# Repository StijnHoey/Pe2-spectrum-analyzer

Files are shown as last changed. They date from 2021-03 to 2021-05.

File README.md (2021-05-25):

# PCB's

## Informatie files:
Gebruikte tekenprogramma: Eagle 9.1.2 \
Eagle files: .sch & .brd \
Gerber files: .zip

### Informatie PCB's:
voedingequ:

Gebruikte Regelaars: LM317 & LM337 \
Emittervolger met zenerdiode: 2n3055

* Ingangsspanning:
  * 12V AC

* Uitgangsspanning:
  * -12V DC
  *   5V DC
  *  12V DC
  *  13v DC   

equlaizer:

Gebruikte OPAMP: LM072 \
Laagdoorlaatfilter en Hoogdoorlaatfilter.\
Samen opgeteld met sommeerversterker.\
Laagdoorlaatfilter voor bass.\
Hoogdoorlaatfilter voor treble. \
Versterking/verzwakking bepaald door digitale potentiometer.\
Digitale quad potentiometer: AD5263. \

Arduinoshield:\
Shield voor arduino om audio in te lezen.\
Voorzien van laagdoorlaatfilter.\
Offset regelbaar tot 3,3V.\

TDA7492:
25W stereo versterker. \
Aan/uit via shutdown pin en mute pin. \

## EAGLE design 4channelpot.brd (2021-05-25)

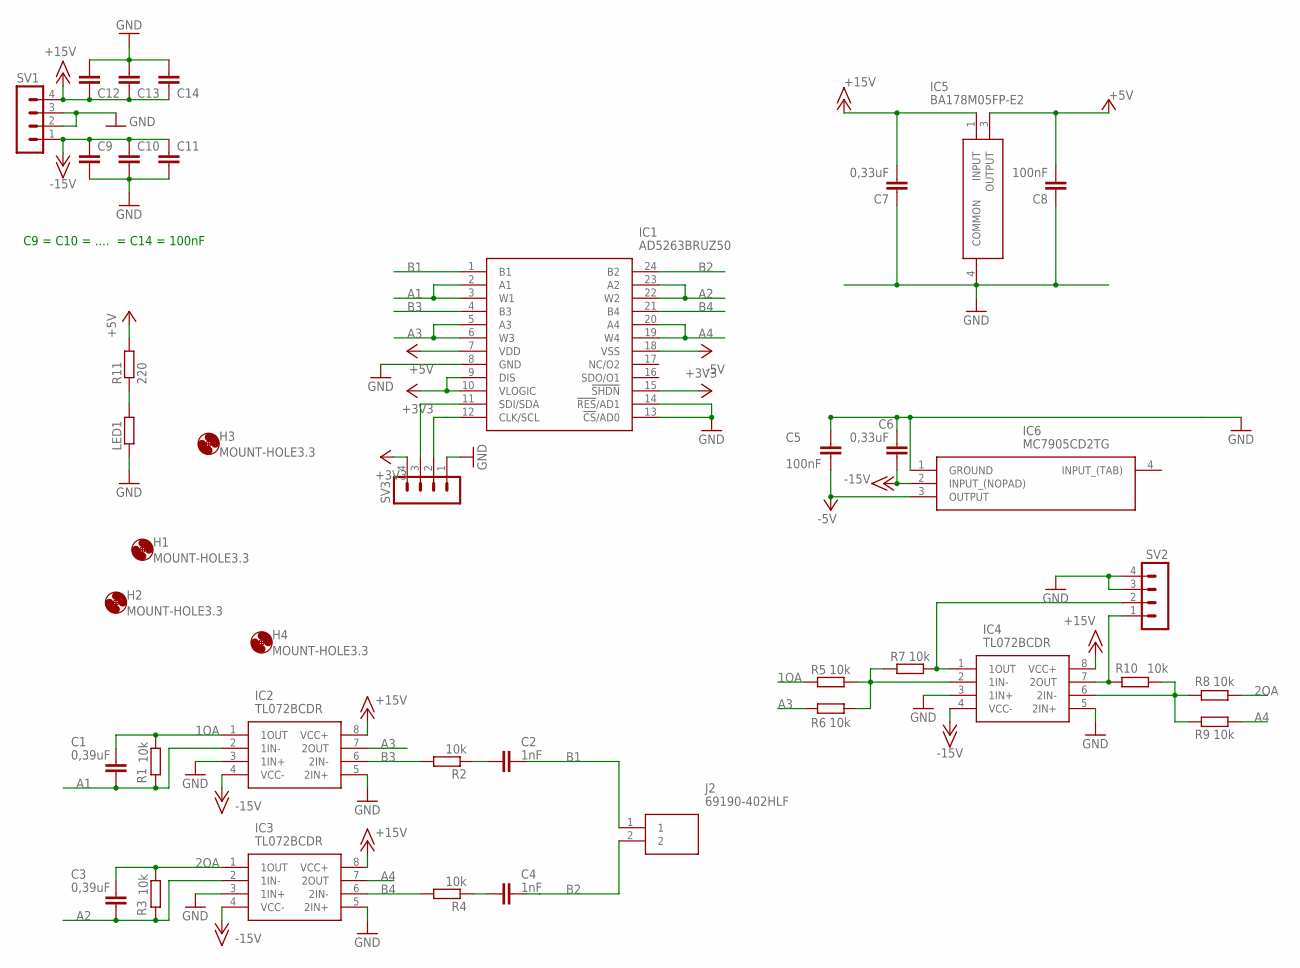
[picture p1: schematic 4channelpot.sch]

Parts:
C1, C3: 0,39uF; C0805
C2, C4: 1nF; C0805
C5, C8: 100nF; C0805
C6, C7: 0,33uF; C0805
C9, C10, C11, C12, C13, C14: C-EUC0805; C0805
H1, H2, H3, H4: MOUNT-HOLE3.3; 3,3
IC1: AD5263BRUZ50; SOP65P640X120-24N
IC2, IC3, IC4: TL072BCDR; SOIC127P600X175-8N
IC5: BA178M05FP-E2; BD750L5FPCE2
IC6: MC7905CD2TG; TO254P1420X457-4N
J2: 69190-402HLF; HDRV2W90P0X254_1X2_508X241X858
LED1: R-EU_R0805; R0805
R1, R2, R3, R4, R5, R6, R7, R8, R9, R10: 10k; R0805
R11: 220; R0805
SV1, SV2, SV3: MA04-1

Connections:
1OA: C1.1, IC2.1 (1OUT), R1.2, R5.2
2OA: C3.1, IC3.1 (1OUT), R3.2, R8.2
+3V3: IC1.9 (DIS), IC1.10 (VLOGIC), IC1.15 (!SHDN), SV3.4
+5V: C8.2, IC1.7 (VDD), IC5.3 (OUTPUT), R11.2
+15V: C7.2, C12.1, C13.1, C14.1, IC2.8 (VCC+), IC3.8 (VCC+), IC4.8 (VCC+), IC5.1 (INPUT), SV1.4
-5V: C5.2, IC1.18 (VSS), IC6.3 (OUTPUT)
-15V: C6.2, C9.1, C10.1, C11.1, IC2.4 (VCC-), IC3.4 (VCC-), IC4.4 (VCC-), IC6.2 (INPUT_(NOPAD)), SV1.1
A1: C1.2, IC1.2 (A1), IC1.3 (W1), IC2.2 (1IN-), R1.1
A2: C3.2, IC1.22 (W2), IC1.23 (A2), IC3.2 (1IN-), R3.1
A3: IC1.5 (A3), IC1.6 (W3), IC2.7 (2OUT), R6.2
A4: IC1.19 (W4), IC1.20 (A4), IC3.7 (2OUT), R9.2
B1: C2.1, IC1.1 (B1), J2.1
B2: C4.1, IC1.24 (B2), J2.2
B3: IC1.4 (B3), IC2.6 (2IN-), R2.2
B4: IC1.21 (B4), IC3.6 (2IN-), R4.2
GND: C5.1, C6.1, C7.1, C8.1, C9.2, C10.2, C11.2, C12.2, C13.2, C14.2, IC1.8 (GND), IC1.13 (!CS!/AD0), IC1.14 (!RES!/AD1), IC2.3 (1IN+), IC2.5 (2IN+), IC3.3 (1IN+), IC3.5 (2IN+), IC4.3 (1IN+), IC4.5 (2IN+), IC5.4 (COMMON), IC6.1 (GROUND), LED1.1, SV1.2, SV1.3, SV2.3, SV2.4, SV3.1
unnamed: IC4.2 (1IN-), R5.1, R6.1, R7.2
unnamed: IC4.1 (1OUT), R7.1, SV2.2
unnamed: LED1.2, R11.1
unnamed: C2.2, R2.1
unnamed: IC4.6 (2IN-), R8.1, R9.1, R10.2
unnamed: IC1.11 (SDI/SDA), SV3.3
unnamed: IC1.12 (CLK/SCL), SV3.2
unnamed: C4.2, R4.1
unnamed: IC4.7 (2OUT), R10.1, SV2.1

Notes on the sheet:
C9 = C10 = .... = C14 = 100nF

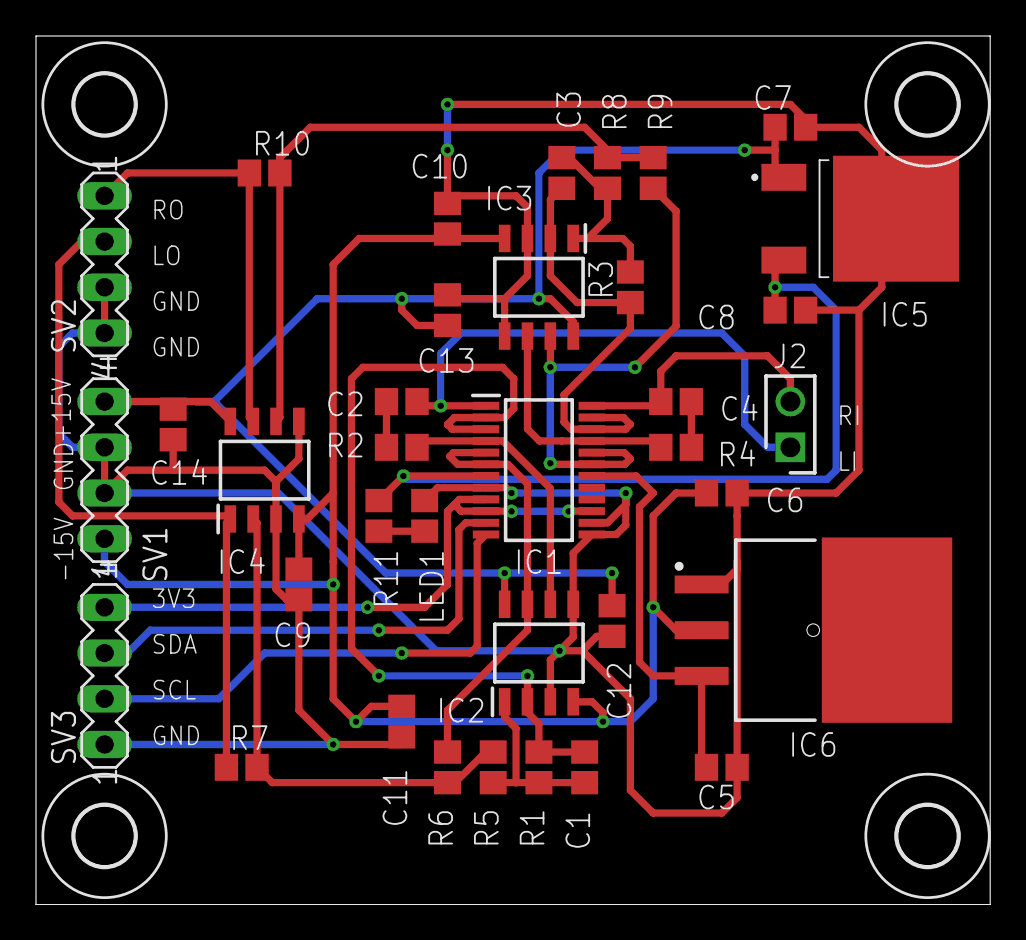
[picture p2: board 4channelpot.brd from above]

Board: 2 copper layers, 53.0 x 48.2 mm, 40 parts (0 on the bottom side), 25 nets.

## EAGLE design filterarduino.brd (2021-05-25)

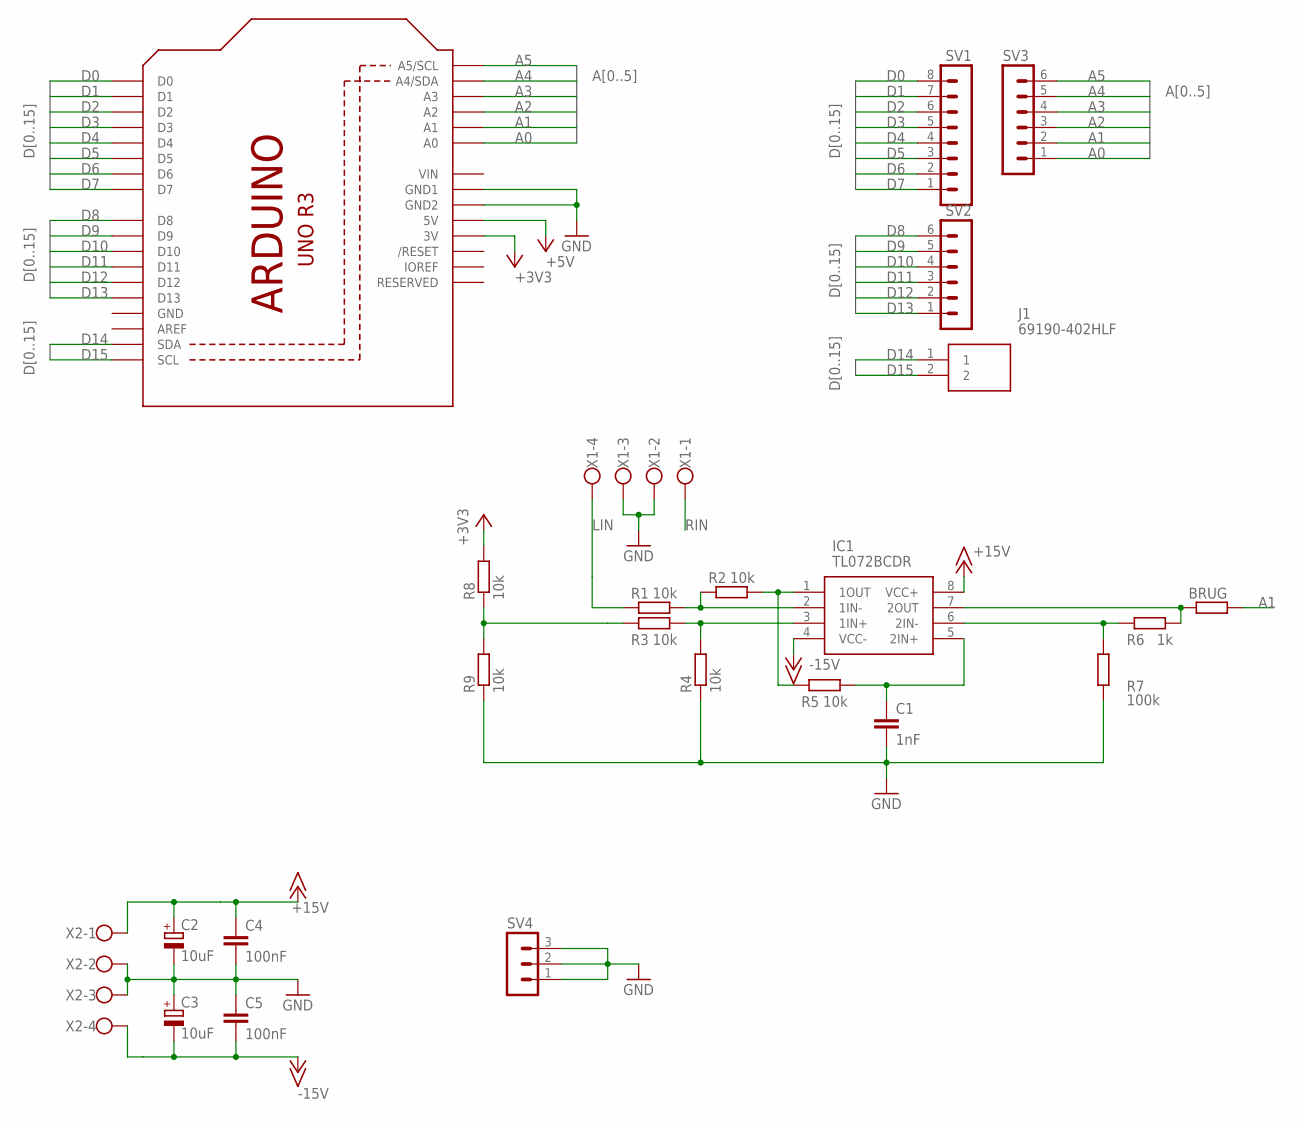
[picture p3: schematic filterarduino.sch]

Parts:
BRUG: 0; R0805
C1: 1nF; C0805
C2, C3: 10uF; 153CLV-0505
C4, C5: 100nF; C0805
IC1: TL072BCDR; SOIC127P600X175-8N
J1: 69190-402HLF; HDRV2W90P0X254_1X2_508X241X858
R1, R2, R3, R4, R5, R8, R9: 10k; R0805
R6: 1k; R0805
R7: 100k; R0805
SV1: MA08-1
SV2, SV3: MA06-1
SV4: MA03-1
U1: ARDUINOR3-BPLACE
X1, X2: W237-4

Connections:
+3V3: R8.2, U1.3V
+5V: U1.5V
+15V: C2.+, C4.1, IC1.8 (VCC+), X2.1
-15V: C3.-, C5.2, IC1.4 (VCC-), X2.4
A0: SV3.1, U1.A0
A1: BRUG.2, SV3.2, U1.A1
A2: SV3.3, U1.A2
A3: SV3.4, U1.A3
A4: SV3.5, U1.A4 (A4/SDA)
A5: SV3.6, U1.A5 (A5/SCL)
D0: SV1.8, U1.D0
D1: SV1.7, U1.D1
D2: SV1.6, U1.D2
D3: SV1.5, U1.D3
D4: SV1.4, U1.D4
D5: SV1.3, U1.D5
D6: SV1.2, U1.D6
D7: SV1.1, U1.D7
D8: SV2.6, U1.D8
D9: SV2.5, U1.D9
D10: SV2.4, U1.D10
D11: SV2.3, U1.D11
D12: SV2.2, U1.D12
D13: SV2.1, U1.D13
D14: J1.1, U1.SDA
D15: J1.2, U1.SCL
GND: C1.2, C2.-, C3.+, C4.2, C5.1, R4.1, R7.1, R9.1, SV4.1, SV4.2, SV4.3, U1.GND, U1.GND1, U1.GND2, X1.2, X1.3, X2.2, X2.3
LIN: R1.1, X1.4
unnamed: IC1.2 (1IN-), R1.2, R2.1
unnamed: IC1.3 (1IN+), R3.2, R4.2
unnamed: IC1.1 (1OUT), R2.2, R5.2
unnamed: C1.1, IC1.5 (2IN+), R5.1
unnamed: BRUG.1, IC1.7 (2OUT), R6.2
unnamed: IC1.6 (2IN-), R6.1, R7.2
unnamed: R3.1, R8.1, R9.2
RIN: X1.1
VIN: U1.VIN

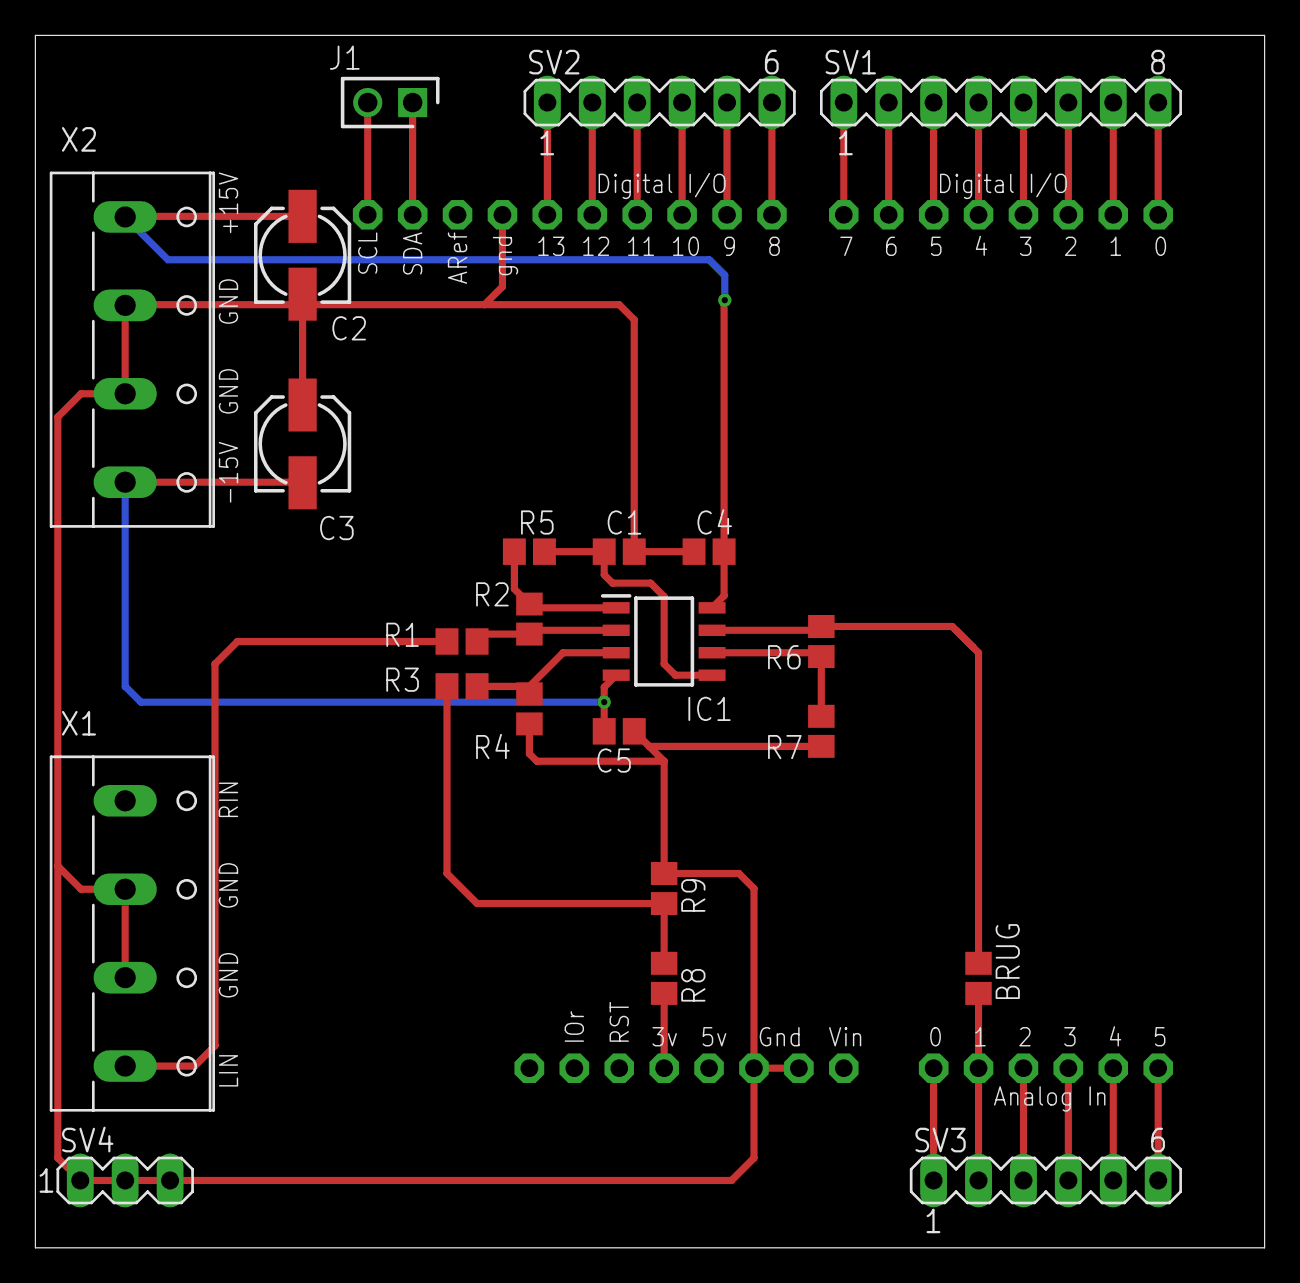
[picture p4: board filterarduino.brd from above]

Board: 2 copper layers, 69.5 x 68.6 mm, 24 parts (0 on the bottom side), 34 nets.

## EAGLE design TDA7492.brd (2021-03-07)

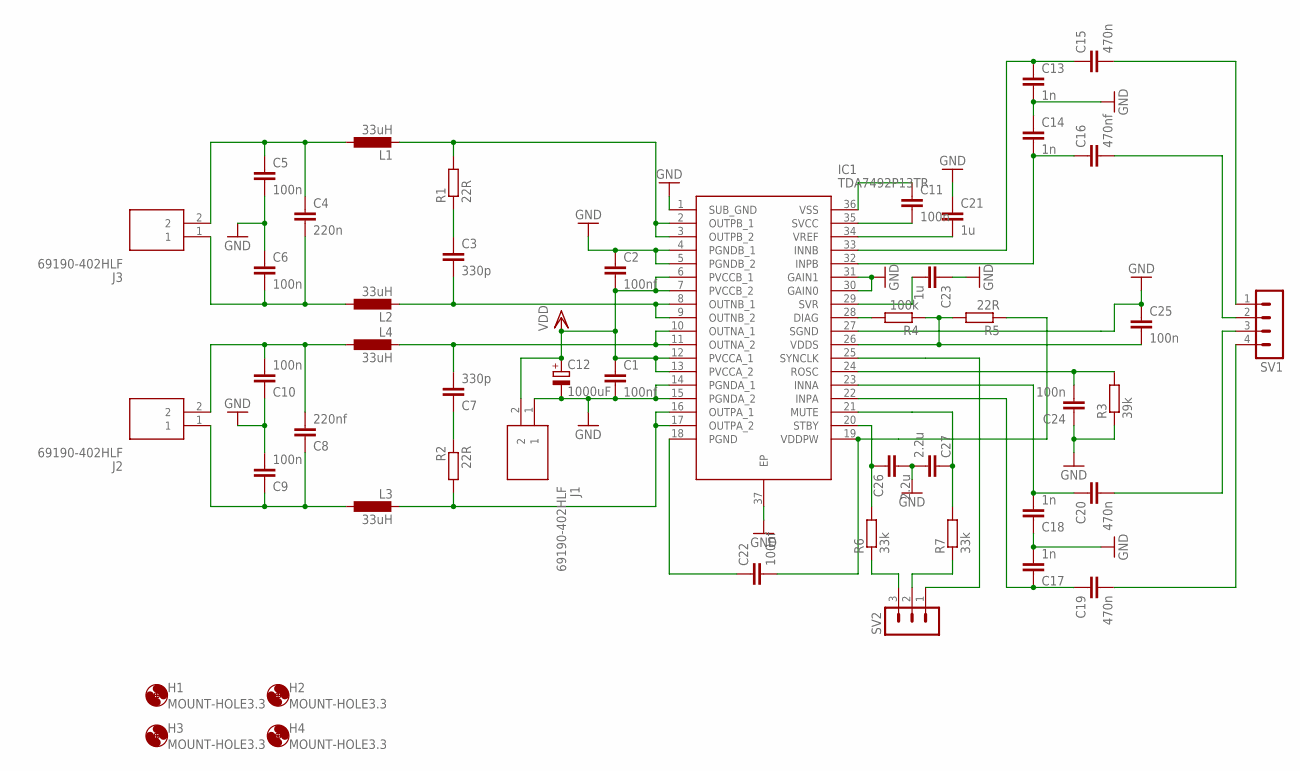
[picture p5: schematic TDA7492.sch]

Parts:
C1, C2, C22: 100nf; C0805
C3, C7: 330p; C0805
C4: 220n; C0805
C5, C6, C9, C10, C11, C24, C25: 100n; C0805
C8: 220nf; C0805
C12: 1000uF; E7,5-16
C13, C14, C17, C18: 1n; C0805
C15, C19, C20: 470n; C0805
C16: 470nf; C0805
C21, C23: 1u; C0805
C26, C27: 2.2u; C0805
H1, H2, H3, H4: MOUNT-HOLE3.3; 3,3
IC1: TDA7492P13TR; SOP50P1030X245-37N
J1, J2, J3: 69190-402HLF; HDRV2W90P0X254_1X2_508X241X858
L1, L2, L3, L4: 33uH; POWER-CHOKE_WE-TPC
R1, R2, R5: 22R; R0805
R3: 39k; R0805
R4: 100k; R0805
R6, R7: 33k; R0805
SV1: MA04-1
SV2: MA03-1

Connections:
GND: C1.2, C2.1, C5.2, C6.1, C9.2, C10.1, C12.-, C13.2, C14.1, C17.2, C18.1, C21.1, C23.1, C24.1, C25.1, C26.2, C27.2, IC1.1 (SUB_GND), IC1.4 (PGNDB_1), IC1.5 (PGNDB_2), IC1.14 (PGNDA_1), IC1.15 (PGNDA_2), IC1.27 (SGND), IC1.30 (GAIN0), IC1.31 (GAIN1), IC1.37 (EP), J1.1, R3.1
unnamed: C4.2, C6.2, J3.1, L2.1
unnamed: C4.1, C5.1, J3.2, L1.1
unnamed: IC1.2 (OUTPB_1), IC1.3 (OUTPB_2), L1.2, R1.2
unnamed: IC1.16 (OUTPA_1), IC1.17 (OUTPA_2), L3.2, R2.2
unnamed: C3.2, IC1.8 (OUTNB_1), IC1.9 (OUTNB_2), L2.2
unnamed: C11.2, IC1.35 (SVCC)
unnamed: C24.2, IC1.24 (ROSC), R3.2
unnamed: C3.1, R1.1
unnamed: C23.2, IC1.29 (SVR)
unnamed: C14.2, C16.1, IC1.32 (INPB)
unnamed: C7.2, IC1.10 (OUTNA_1), IC1.11 (OUTNA_2), L4.2
unnamed: C8.2, C10.2, J2.2, L4.1
unnamed: C8.1, C9.1, J2.1, L3.1
unnamed: C7.1, R2.1
unnamed: C11.1, IC1.36 (VSS)
unnamed: C13.1, C15.1, IC1.33 (INNB)
unnamed: C22.1, IC1.18 (PGND)
unnamed: C17.1, C19.1, IC1.22 (INPA)
unnamed: C21.2, IC1.34 (VREF)
unnamed: C18.2, C20.1, IC1.23 (INNA)
unnamed: C22.2, IC1.19 (VDDPW), R5.1
unnamed: C15.2, SV1.1
unnamed: C16.2, SV1.2
unnamed: C20.2, SV1.3
unnamed: C19.2, SV1.4
unnamed: C27.1, IC1.21 (MUTE), R7.2
unnamed: IC1.28 (DIAG), R4.2
unnamed: C25.2, IC1.26 (VDDS), R4.1, R5.2
unnamed: IC1.25 (SYNCLK), SV2.1
unnamed: C26.1, IC1.20 (STBY), R6.2
unnamed: R6.1, SV2.3
unnamed: R7.1, SV2.2
VDD: C1.1, C2.2, C12.+, IC1.6 (PVCCB_1), IC1.7 (PVCCB_2), IC1.12 (PVCCA_1), IC1.13 (PVCCA_2), J1.2

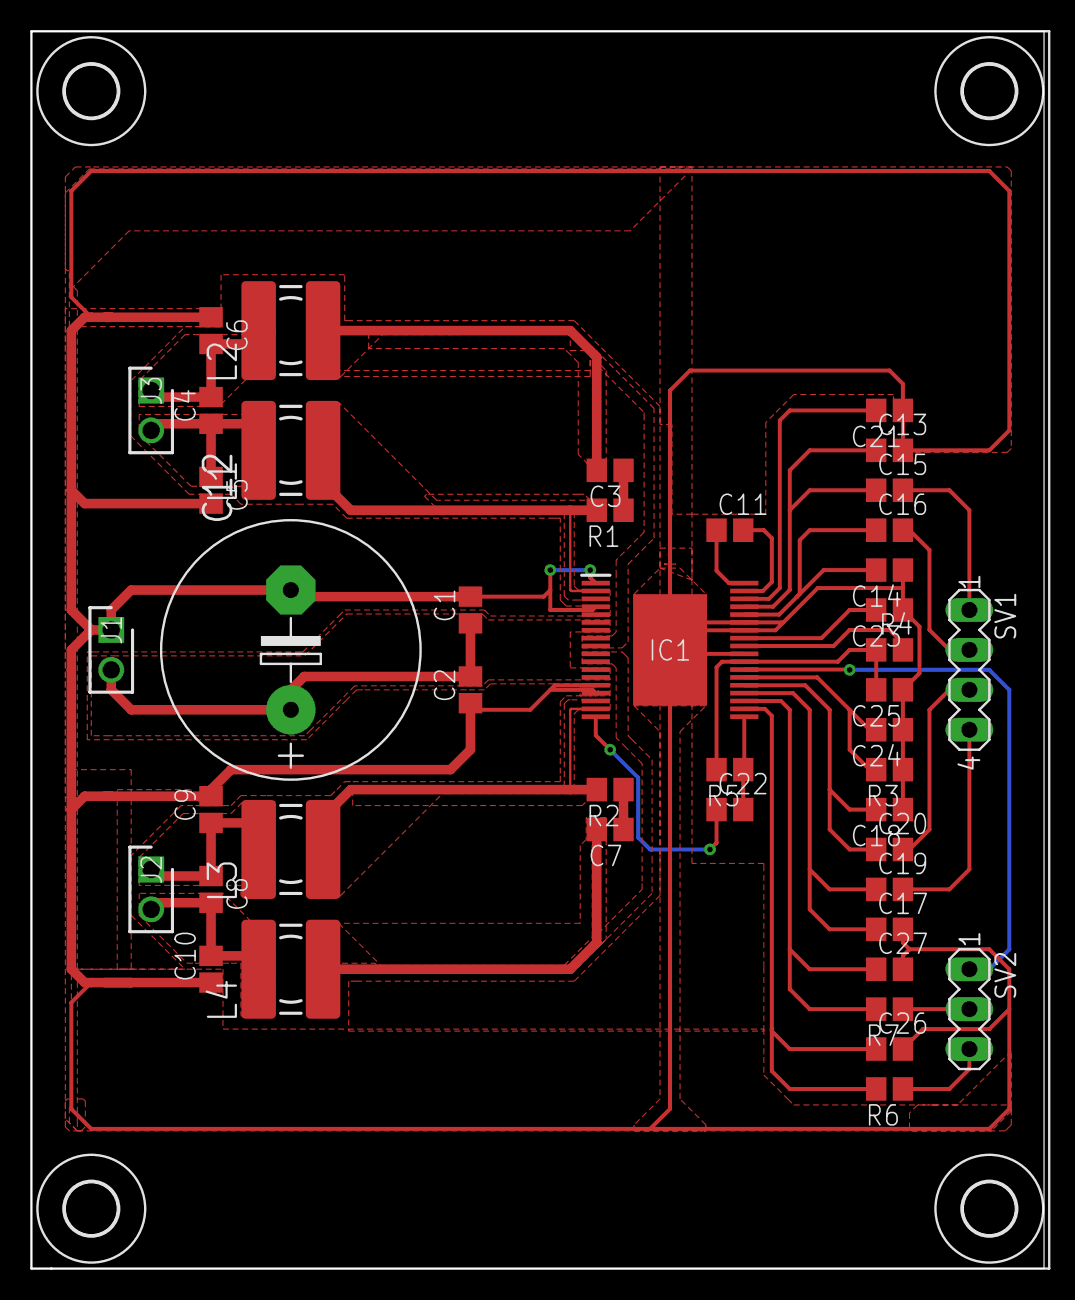
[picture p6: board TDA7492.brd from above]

Board: 2 copper layers, 64.4 x 78.7 mm, 48 parts (0 on the bottom side), 34 nets.

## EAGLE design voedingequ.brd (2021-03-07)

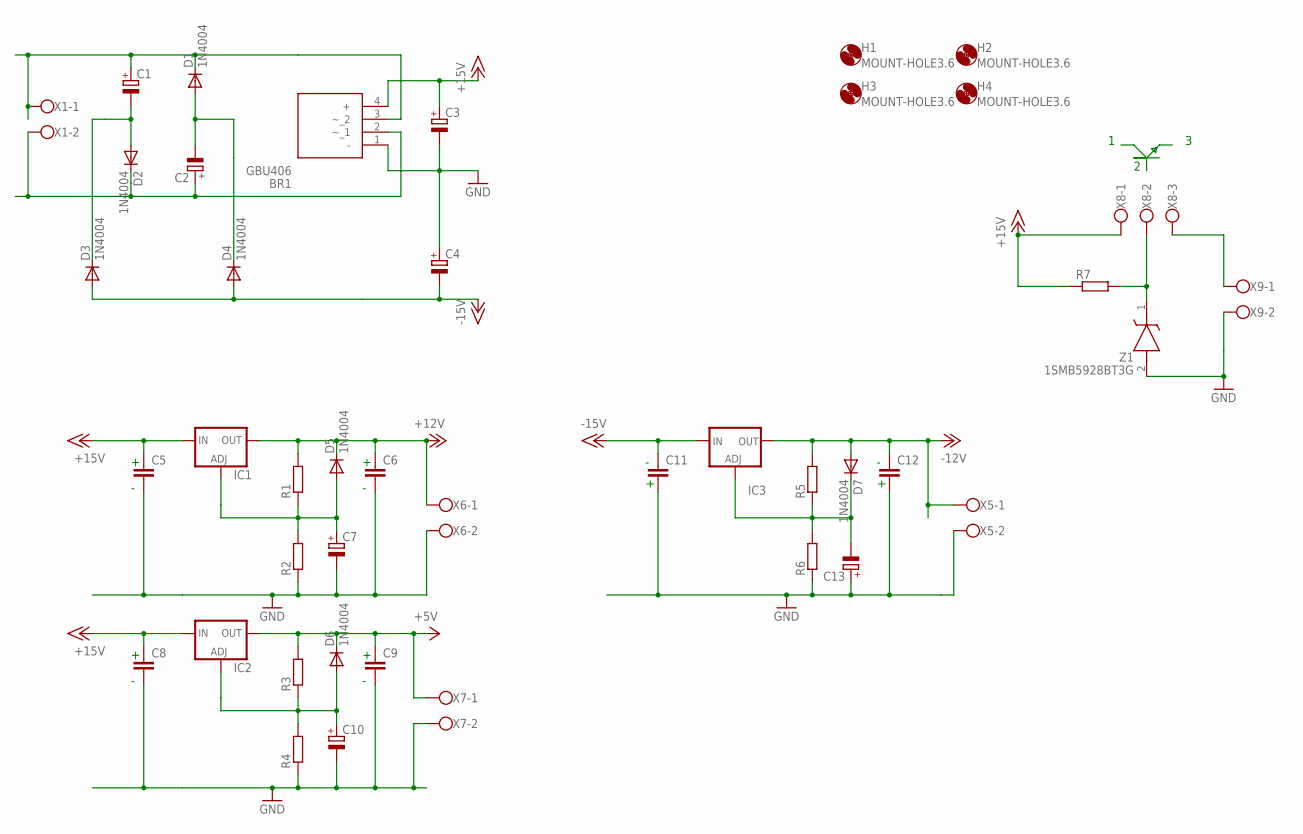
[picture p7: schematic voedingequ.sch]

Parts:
BR1: GBU406; TO508P356X2205X2135-4P
C1, C2, C3, C4: CPOL-EUE5-10.5; E5-10,5
C5, C6, C8, C9, C11, C12: C-EUC0805; C0805
C7, C10, C13: CPOL-EU153CLV-0505; 153CLV-0505
D1, D2, D3, D4, D5, D6, D7: 1N4004; DO41-10
H1, H2, H3, H4: MOUNT-HOLE3.6; 3,6
IC1, IC2: LM317TS; 317TS
IC3: LM337TS; 337TS
R1, R2, R3, R4, R5, R6: R-EU_R0805; R0805
R7: R-EU_R2512; R2512
X1, X5, X6, X7, X9: W237-102
X8: W237-103
Z1: 1SMB5928BT3G; DIOM5436X247N

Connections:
+5V: C9.1, D6.C, IC2.2 (OUT), R3.2, X7.1
+12V: C6.1, D5.C, IC1.2 (OUT), R1.2, X6.1
+15V: BR1.4 (+), C3.+, C5.1, C8.1, IC1.3 (IN), IC2.3 (IN), R7.1, X8.1
-12V: C12.1, D7.A, IC3.3 (OUT), R5.2, X5.1
-15V: C4.-, C11.1, D3.A, D4.A, IC3.2 (IN)
GND: BR1.1 (-), C3.-, C4.+, C5.2, C6.2, C7.-, C8.2, C9.2, C10.-, C11.2, C12.2, C13.+, R2.1, R4.1, R6.1, X5.2, X6.2, X7.2, X9.2, Z1.2 (A)
unnamed: C1.-, D2.A, D3.C
unnamed: C2.-, D1.A, D4.C
unnamed: BR1.3 (~_2), C1.+, D1.C, X1.1
unnamed: BR1.2 (~_1), C2.+, D2.C, X1.2
unnamed: C13.-, D7.C, IC3.1 (ADJ), R5.1, R6.2
unnamed: C7.+, D5.A, IC1.1 (ADJ), R1.1, R2.2
unnamed: X8.3, X9.1
unnamed: R7.2, X8.2, Z1.1 (K)
unnamed: C10.+, D6.A, IC2.1 (ADJ), R3.1, R4.2

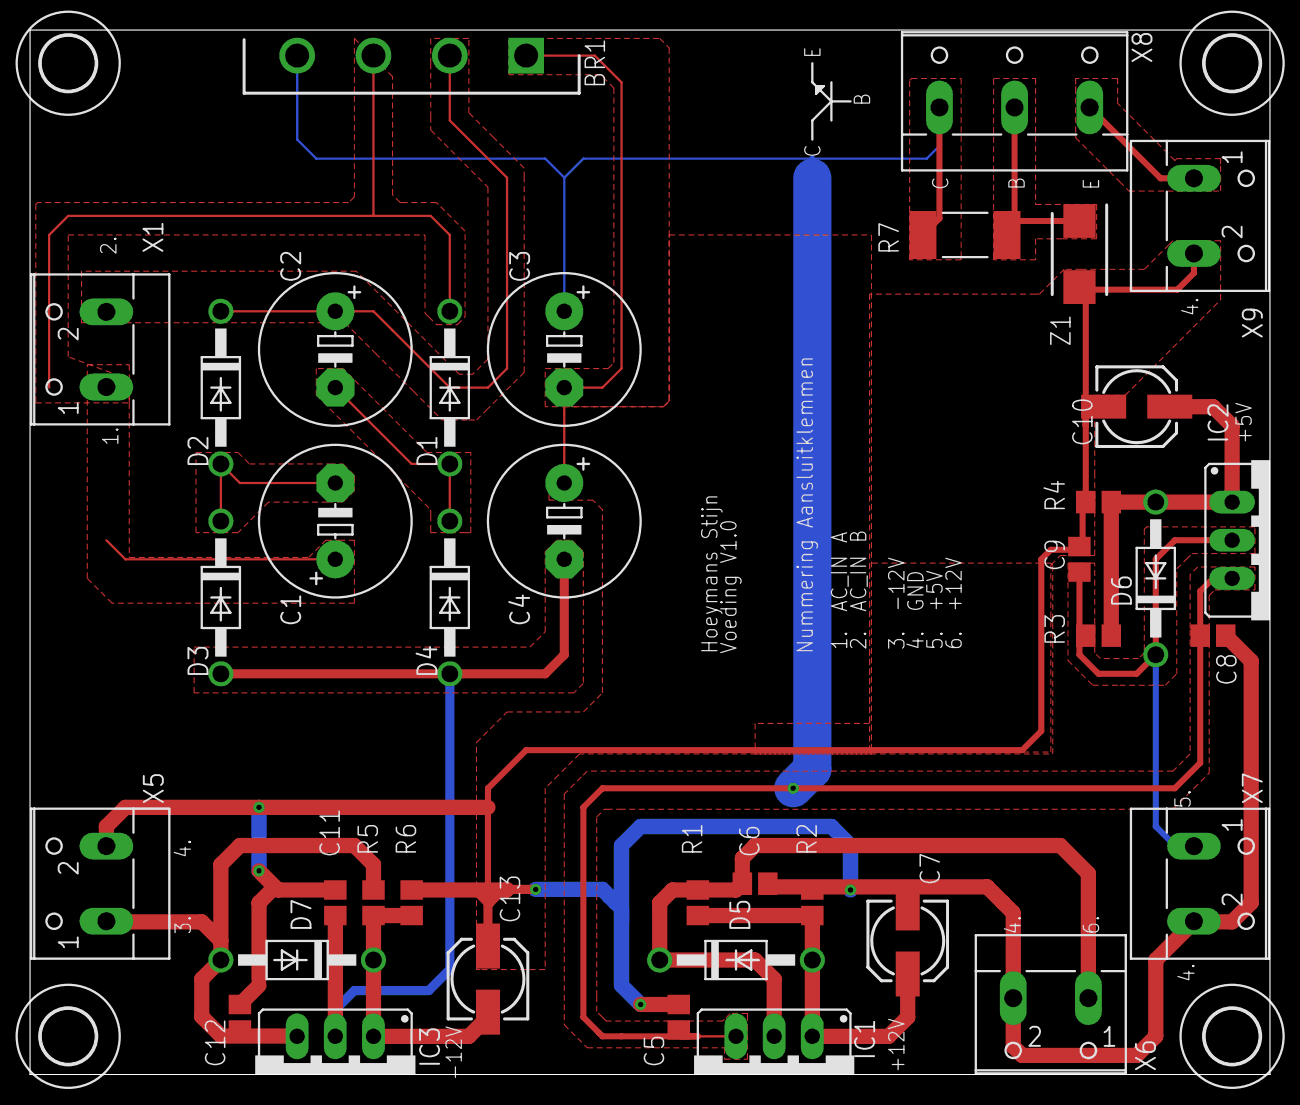
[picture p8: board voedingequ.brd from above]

Board: 2 copper layers, 82.5 x 69.5 mm, 42 parts (0 on the bottom side), 15 nets.
